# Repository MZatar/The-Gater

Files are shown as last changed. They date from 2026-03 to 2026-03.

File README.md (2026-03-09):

# The Gater 🕹️

A physical logic gate explorer built entirely with raw 74LS-series logic. No microcontrollers. No code. Just pure digital logic hardware.

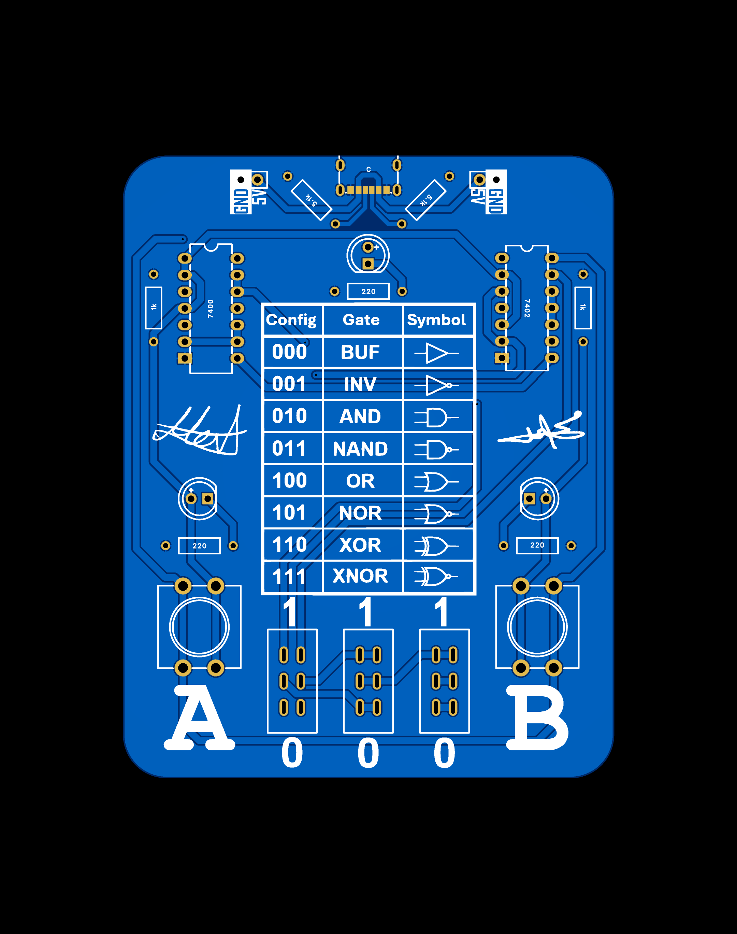
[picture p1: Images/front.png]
Front of PCB
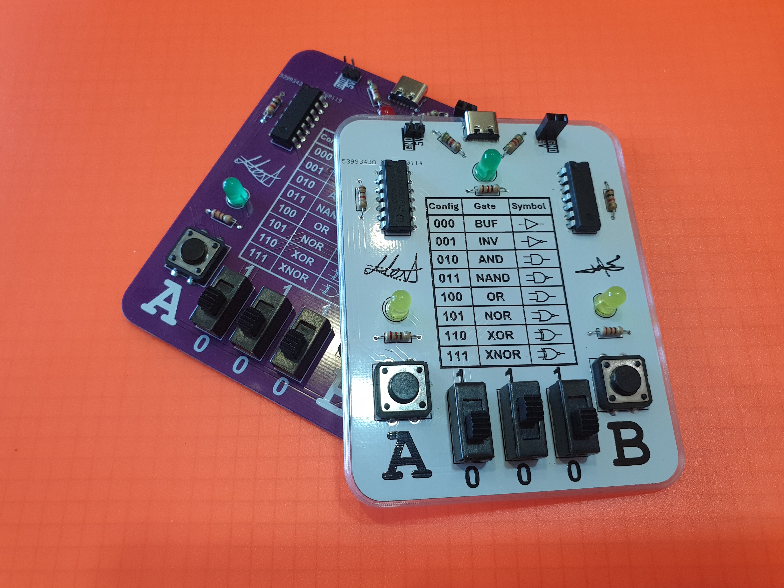
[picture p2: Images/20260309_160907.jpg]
real
    

## What is it?
The Gater is an educational PCB that physically demonstrates all 8 standard logic gate configurations (BUF, INV, AND, NAND, OR, NOR, XOR, XNOR) using only one `74LS00` (Quad NAND) and one `74LS02` (Quad NOR). 

Three DPDT toggle switches physically reroute the logic paths to mimic the desired gate, while dual push buttons provide the inputs.

## Features
* **100% Hardware Logic:** Relies purely on combinational routing between NAND and NOR gates.
* **8 Gate Modes:** Configurable via a 3-switch binary input (000 to 111).
* **Modern Power:** USB-C compatible (with proper 5.1kΩ CC pull-down resistors for C-to-C cable support) alongside standard pin headers.
* **Built-in Cheat Sheet:** Silkscreen truth tables for all gates right on the back.
* **Transparent Case:** Designed for a 3D-printed transparent PETG cover.

## Hardware Configuration
| Config (Switches) | Gate Configured |
| :--- | :--- |
| `000` | Buffer |
| `001` | Inverter (NOT) |
| `010` | AND |
| `011` | NAND |
| `100` | OR |
| `101` | NOR |
| `110` | XOR |
| `111` | XNOR |

## How to Build It
1. **Fabrication:** Grab the `.zip` file and upload it to your favorite PCB manufacturer (JLCPCB, PCBWay, etc.).
2. **Components:** Check the `BOM.csv` folder for exact parts.
3. **Assembly:** Solder the SMDs first (Type-C port), then move to the through-hole components.
4. **Case:** (optional) Print the `Gater_Case.stl` using transparent filament.

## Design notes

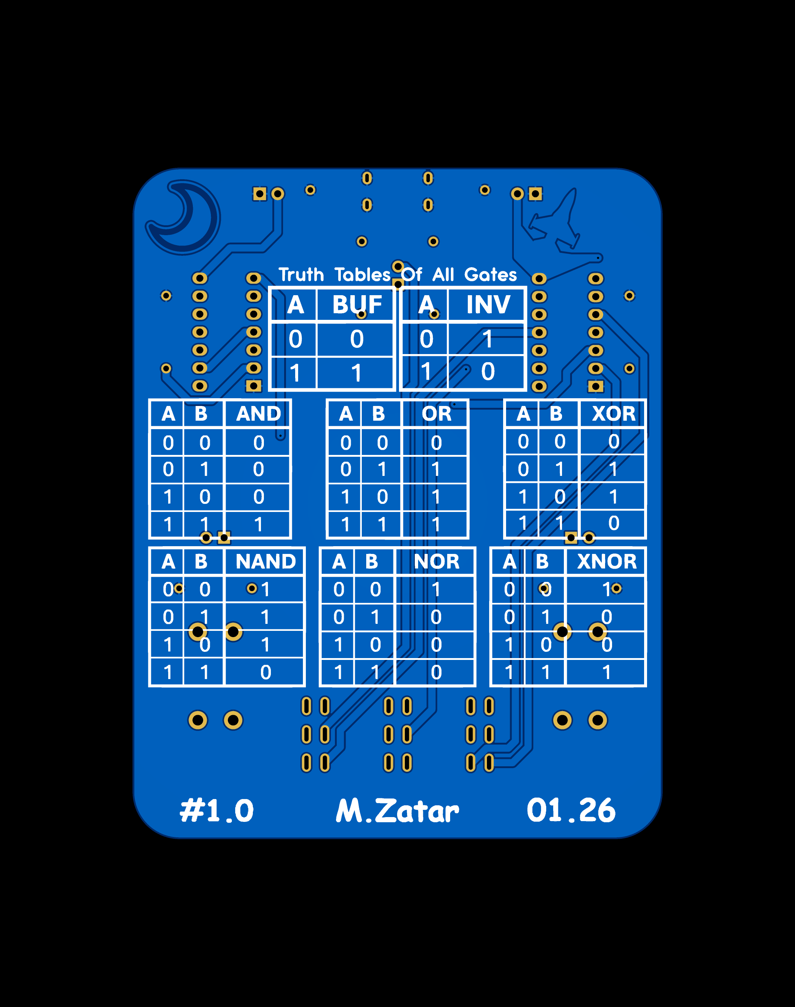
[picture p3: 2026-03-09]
Images/back.png

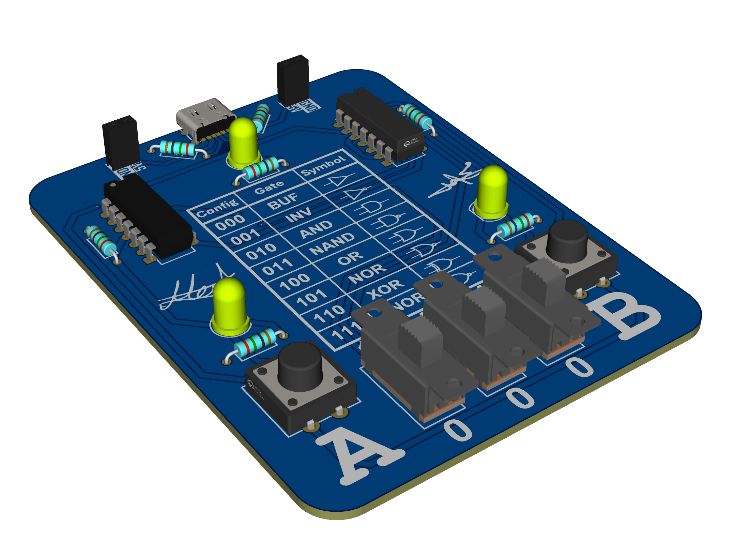
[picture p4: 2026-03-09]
Images/3D_PCB1.png

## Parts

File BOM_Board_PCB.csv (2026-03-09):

No. | Quantity | Designator | Footprint | Value | Manufacturer Part | Manufacturer | Supplier Part | Supplier | 3D Model Title | Comment
1 | 2 | 1k,1k | RES-TH_BD2.4-L6.3-P10.30-D0.6 | 1kΩ | RD1/4W1KJT/BA1 | Tyohm(幸亚电阻) | C433779 | LCSC | RES-TH_BD2.4-L6.3-P10.30-D0.6 | 1kΩ
2 | 2 | 5.1k,5.1k | RES-TH_BD2.4-L6.3-P10.30-D0.6 | 5.1kΩ | RD 1/4W 5K1 J T/B A1 | Tyohm(幸亚电阻) | C433710 | LCSC | RES-TH_BD2.4-L6.3-P10.30-D0.6 | 5.1kΩ
3 | 3 | 220,220,220 | RES-TH_BD2.4-L6.3-P10.30-D0.6 | 220Ω | RD 1/4W 220R J T/B A1 | Tyohm(幸亚电阻) | C433749 | LCSC | RES-TH_BD2.4-L6.3-P10.30-D0.6 | 220Ω
4 | 1 | 7400 | PDIP-14_L19.7-W6.6-P2.54-LS8.3-BL |  | SN74LS00N | TI(德州仪器) | C181629 | LCSC | PDIP-14_L19.7-W6.6-H5.1-P2.54-LS8.3-BL | SN74LS00N
5 | 1 | 7402 | PDIP-14_L19.3-W6.4-P2.54-LS7.6-BL |  | SN74LS02N | TI(德州仪器) | C273654 | LCSC | PDIP-14_L19.3-W6.4-P2.54-LS7.6-BL | SN74LS02N
6 | 1 | C | USB-C-SMD_HX-TYPE-C-6PIN |  | HX TYPE-C 6PIN | hanxia(韩下) | C18357552 | LCSC | USB Connector Type C female 6pin | HX TYPE-C 6PIN
7 | 3 | LED1,LED2,LED3 | LED-TH_BD5.8-P2.54-FD |  |  |  |  |  | LED-TH_5mm_YG | LED_TH-R_5mm
8 | 2 | P1,p2 | HDR-TH_2P-P2.54-V-F |  | 2.54-1*2P母 | BOOMELE(博穆精密) | C49661 | LCSC | HDR-TH_2P-P2.54-F-LI-1X2P | 2.54-1*2P母
9 | 3 | SW6,SW7,SW8 | SW-TH_SS-22F25-G050 |  | SS-22F32-G060 | G-Switch(品赞) | C2848931 | LCSC | SW-TH_SS-22F25-G050 | SS-22F32-G060
10 | 2 | SW9,SW10 | SW-TH_4P-L12.0-W12.0-P5.00-LS12.5 |  | TSF001B05526A03 | BZCN(博众电气) | C2888839 | LCSC | SW-TH_4P-L12.0-W12.0-P5.00-LS12.5 | TSF001B05526A03

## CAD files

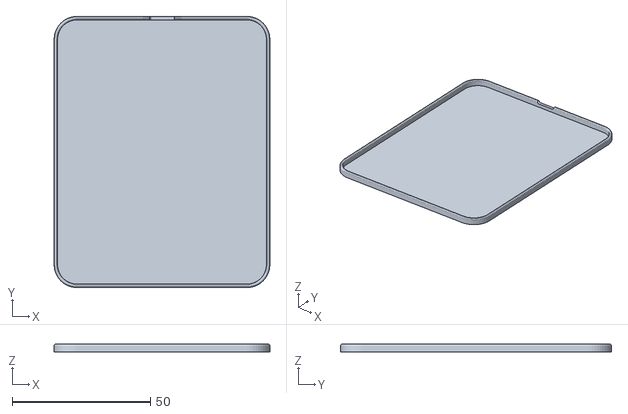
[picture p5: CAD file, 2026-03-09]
Gater_Case.stl
78.1 x 98.1 x 2.82

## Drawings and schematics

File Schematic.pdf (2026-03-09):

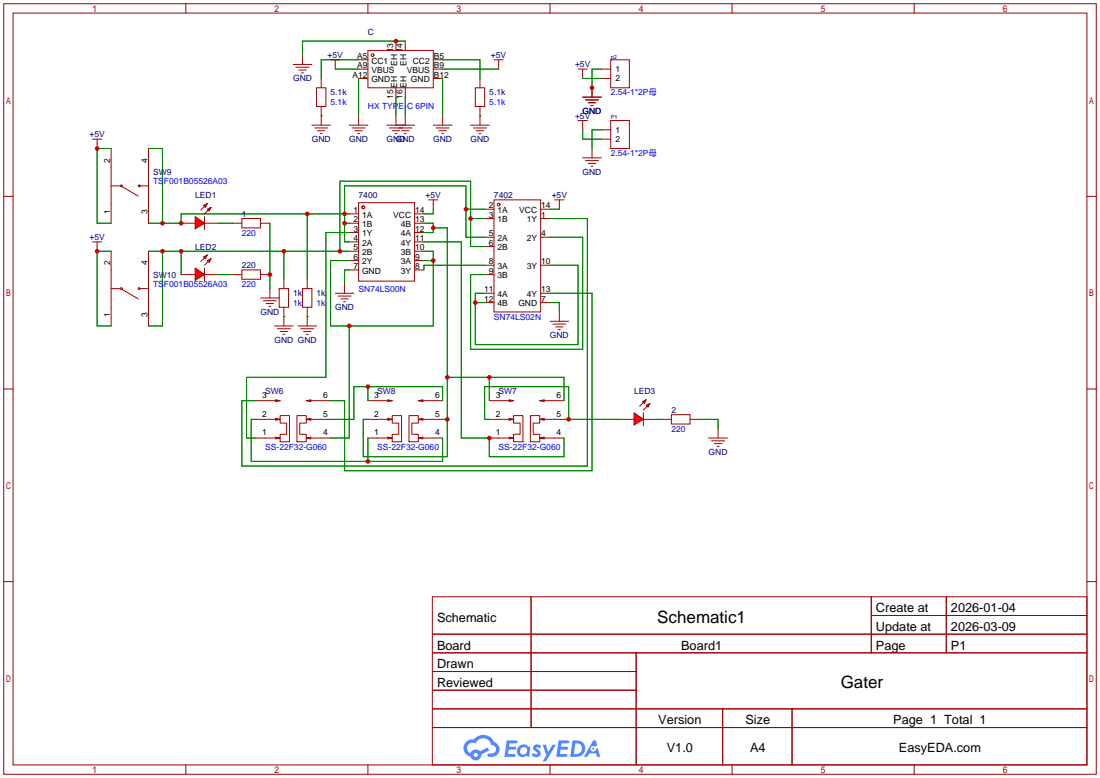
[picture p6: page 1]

GND B12 VBUS B9 CC2 B5

Schematic | Schematic1 | Create at | 2026-01-04

Update at | 2026-03-09

Board | Board1 | Page | P1
Drawn | | Gater
Reviewed

Version | Size | Page 1 Total 1
V1.0 | A4 | EasyEDA.com
